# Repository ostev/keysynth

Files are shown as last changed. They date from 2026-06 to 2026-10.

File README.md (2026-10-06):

# KeySynth

KeySynth is an equation synthesiser built around a traditional mechanical keyboard!

An equation synthesiser is a wavetable synthesiser that allows the user to input arbitrary mathematical expressions which can then be used to create sounds! It also features a basic low-pass filter, with more effects (hopefully) to come.

In addition, it can act as a regular computer keyboard.

This repository contains the open-source PCBs (missing non-open source components from UltraLibrarian and SnapMagic) as well as project's source code. The PCB contains an 80% keyboard, three knobs, a pinout for a display, an ESP32-S3 (used for audio, display and USB) and an RP2040 (used for interfacing with the keyboard matrix due to limited pin availability).

The source code is divided into the following crates:

- [`calc`](crates/calc/) for the tiny programming language used for synthesis,
- [`repl`](crates/repl/) for a simple REPL for `calc` which is used for debugging and implementing new langauge features,
- [`synth`](crates/synth/) for the audio engine,
- [`keyboard_protocol`](crates/keyboard_protocol/) for interfacing between the RP2040 and the ESP32-S3 about keyboards and two of the three knobs over UART serial,
- [`keyboard_rp2040`](crates/keyboard_rp2040/) for running the keyboard matrix on the RP2040, and
- [`app`](crates/app/) for running the main application on the ESP32-S3.

## Demo

There'll be a link to a video demo up on YouTube once I've filmed it.

## :construction: :construction: :construction: Roadmap

This project isn't finished! Equation synthesis and keyboard input all work, but I want to implement some more features before considering it complete:

- [ ] USB MIDI input from host
- [ ] Improve PCB layout (as-is there are a couple of design flaws that don't inhabit the current set of functionality but limit the utility of 3.5mm audio output. I'm not sure when I'll be able to fix this: it'll be when I've made enough changes that I can justify the cost of ordering another set of PCBs.)
- [ ] Add more audio effects, like reverb and chorus.
- [ ] Add more audio synthesis engines, like subtractive or FM synthesis.

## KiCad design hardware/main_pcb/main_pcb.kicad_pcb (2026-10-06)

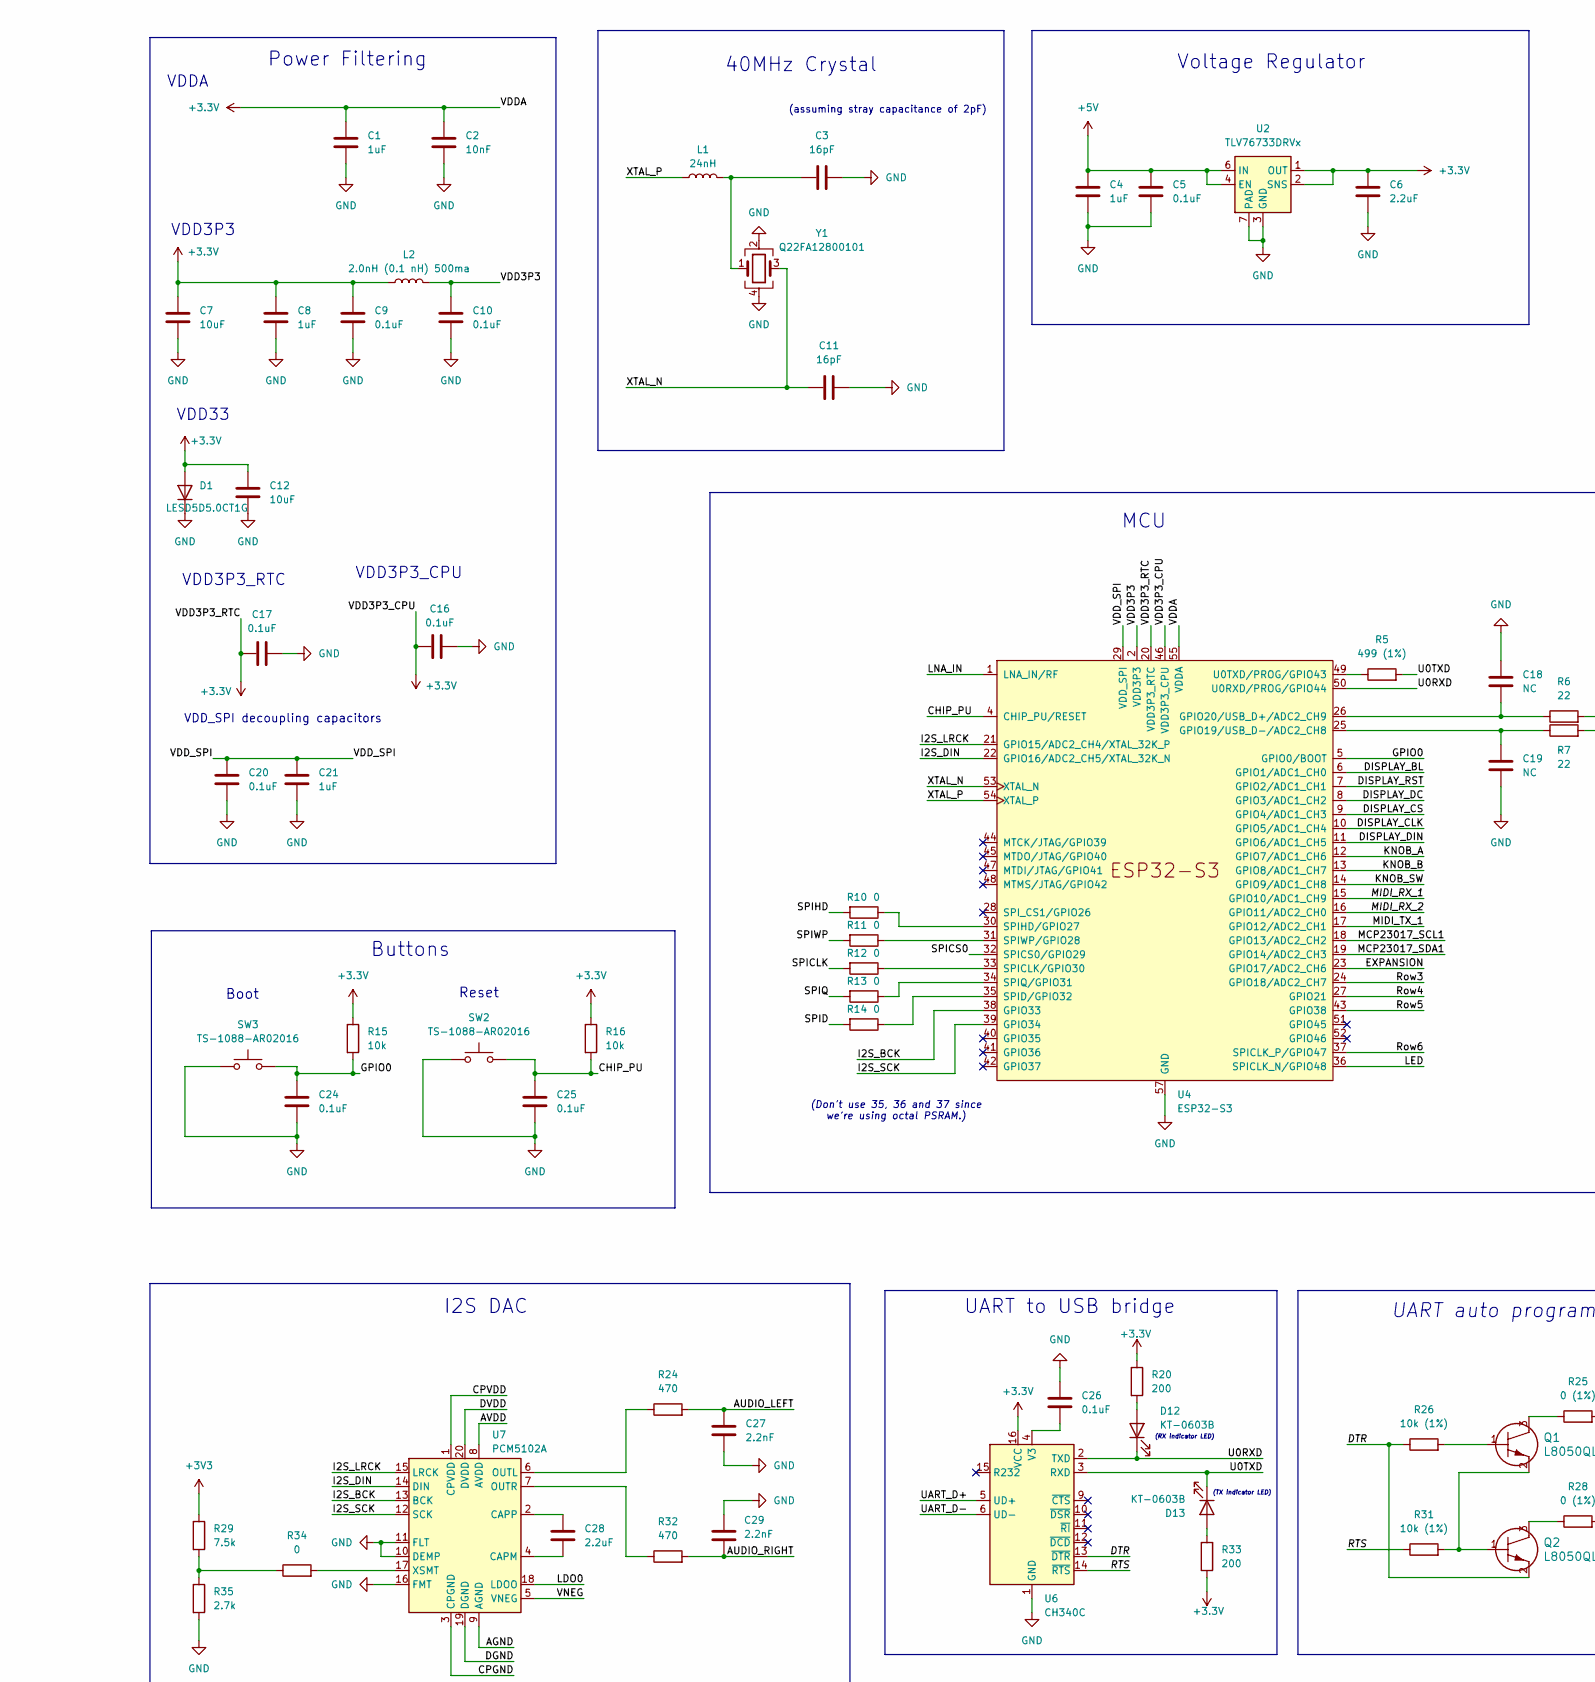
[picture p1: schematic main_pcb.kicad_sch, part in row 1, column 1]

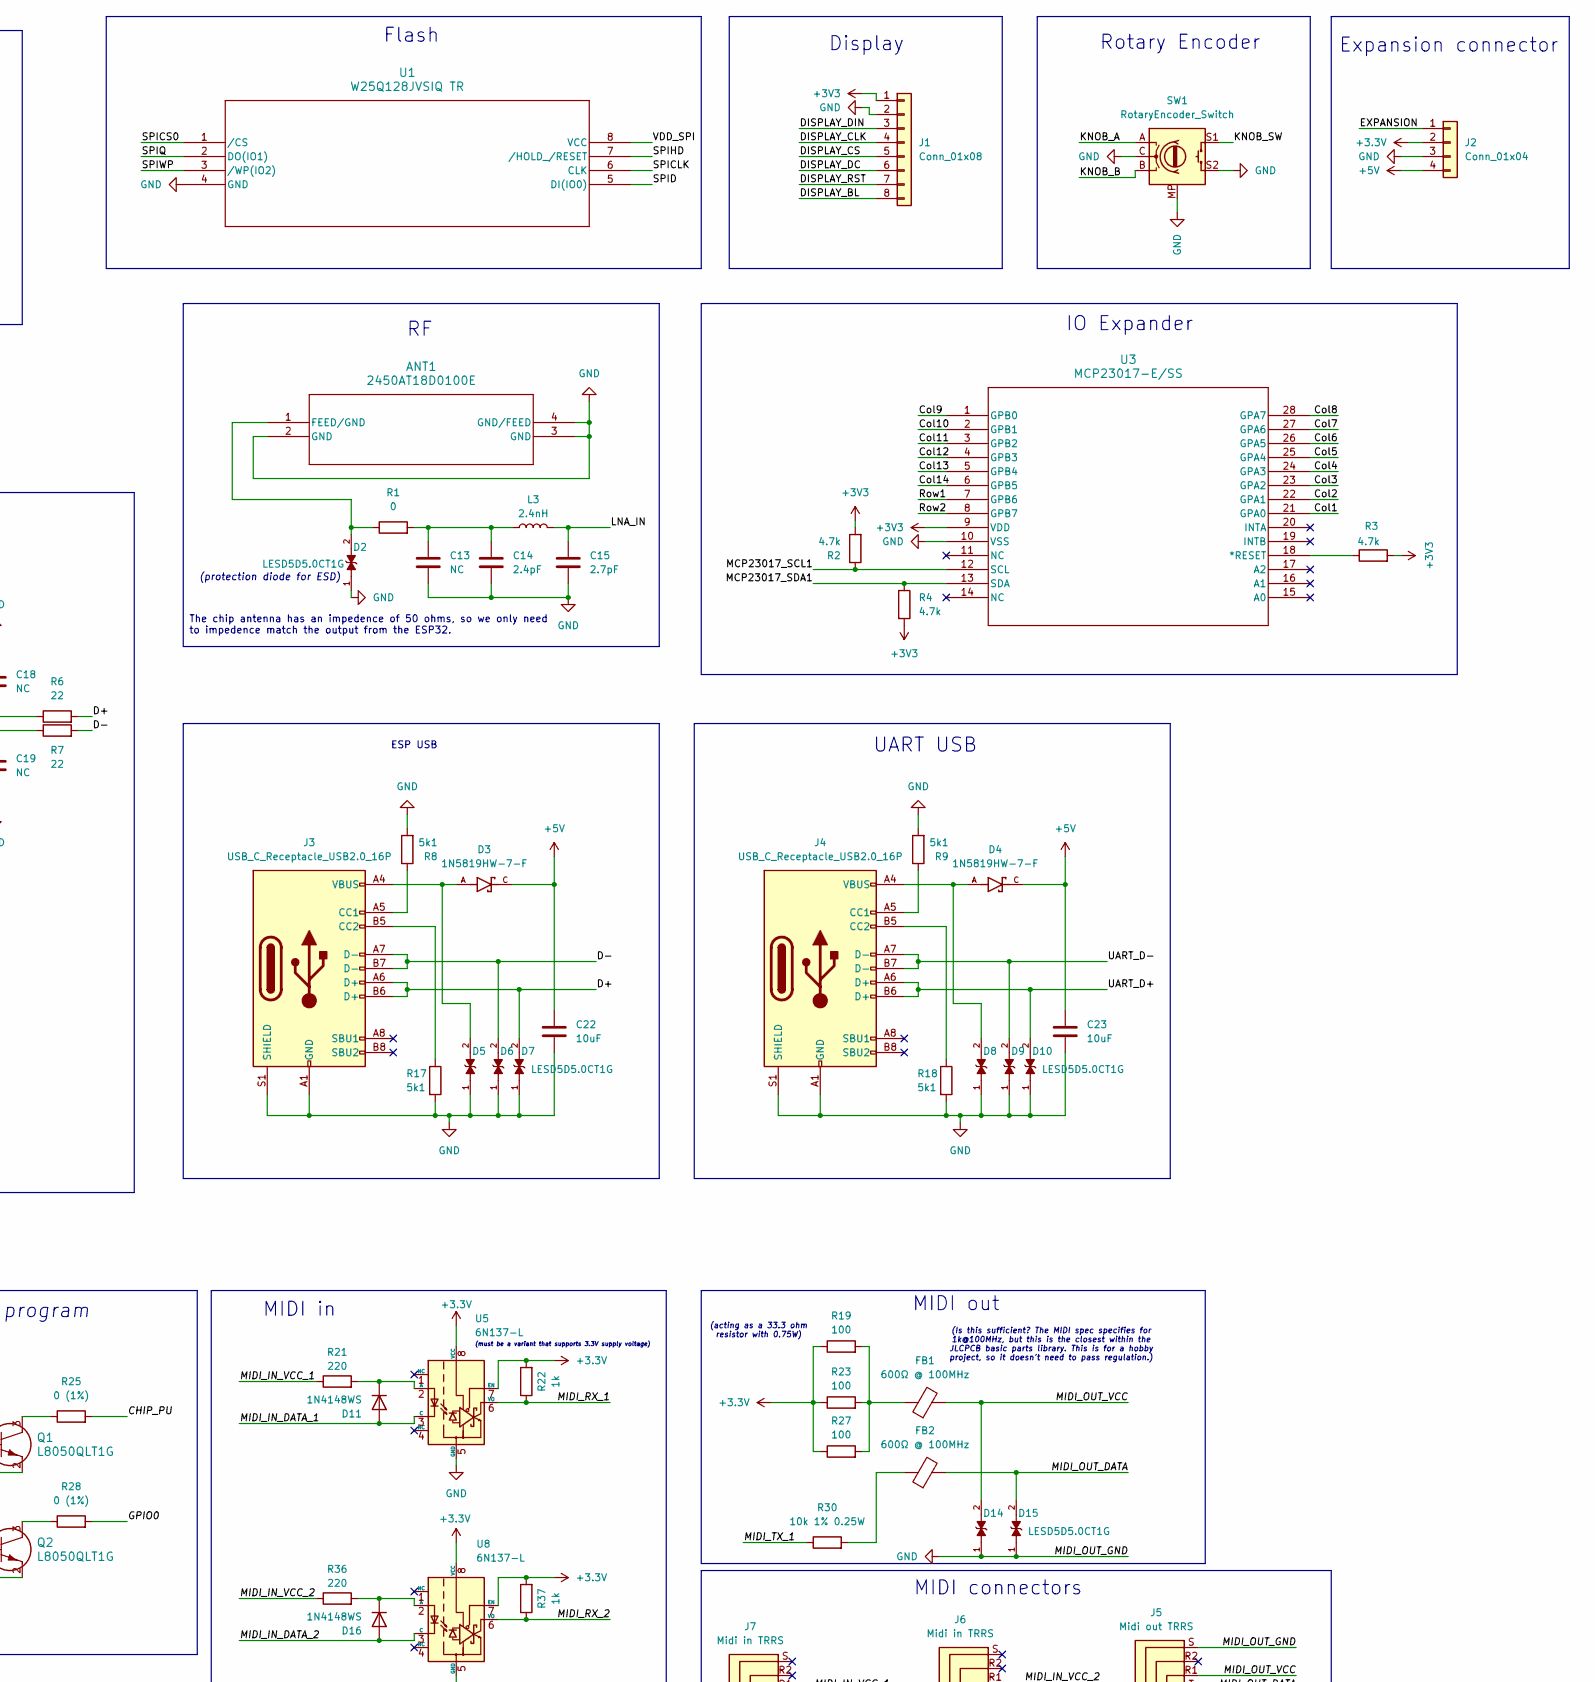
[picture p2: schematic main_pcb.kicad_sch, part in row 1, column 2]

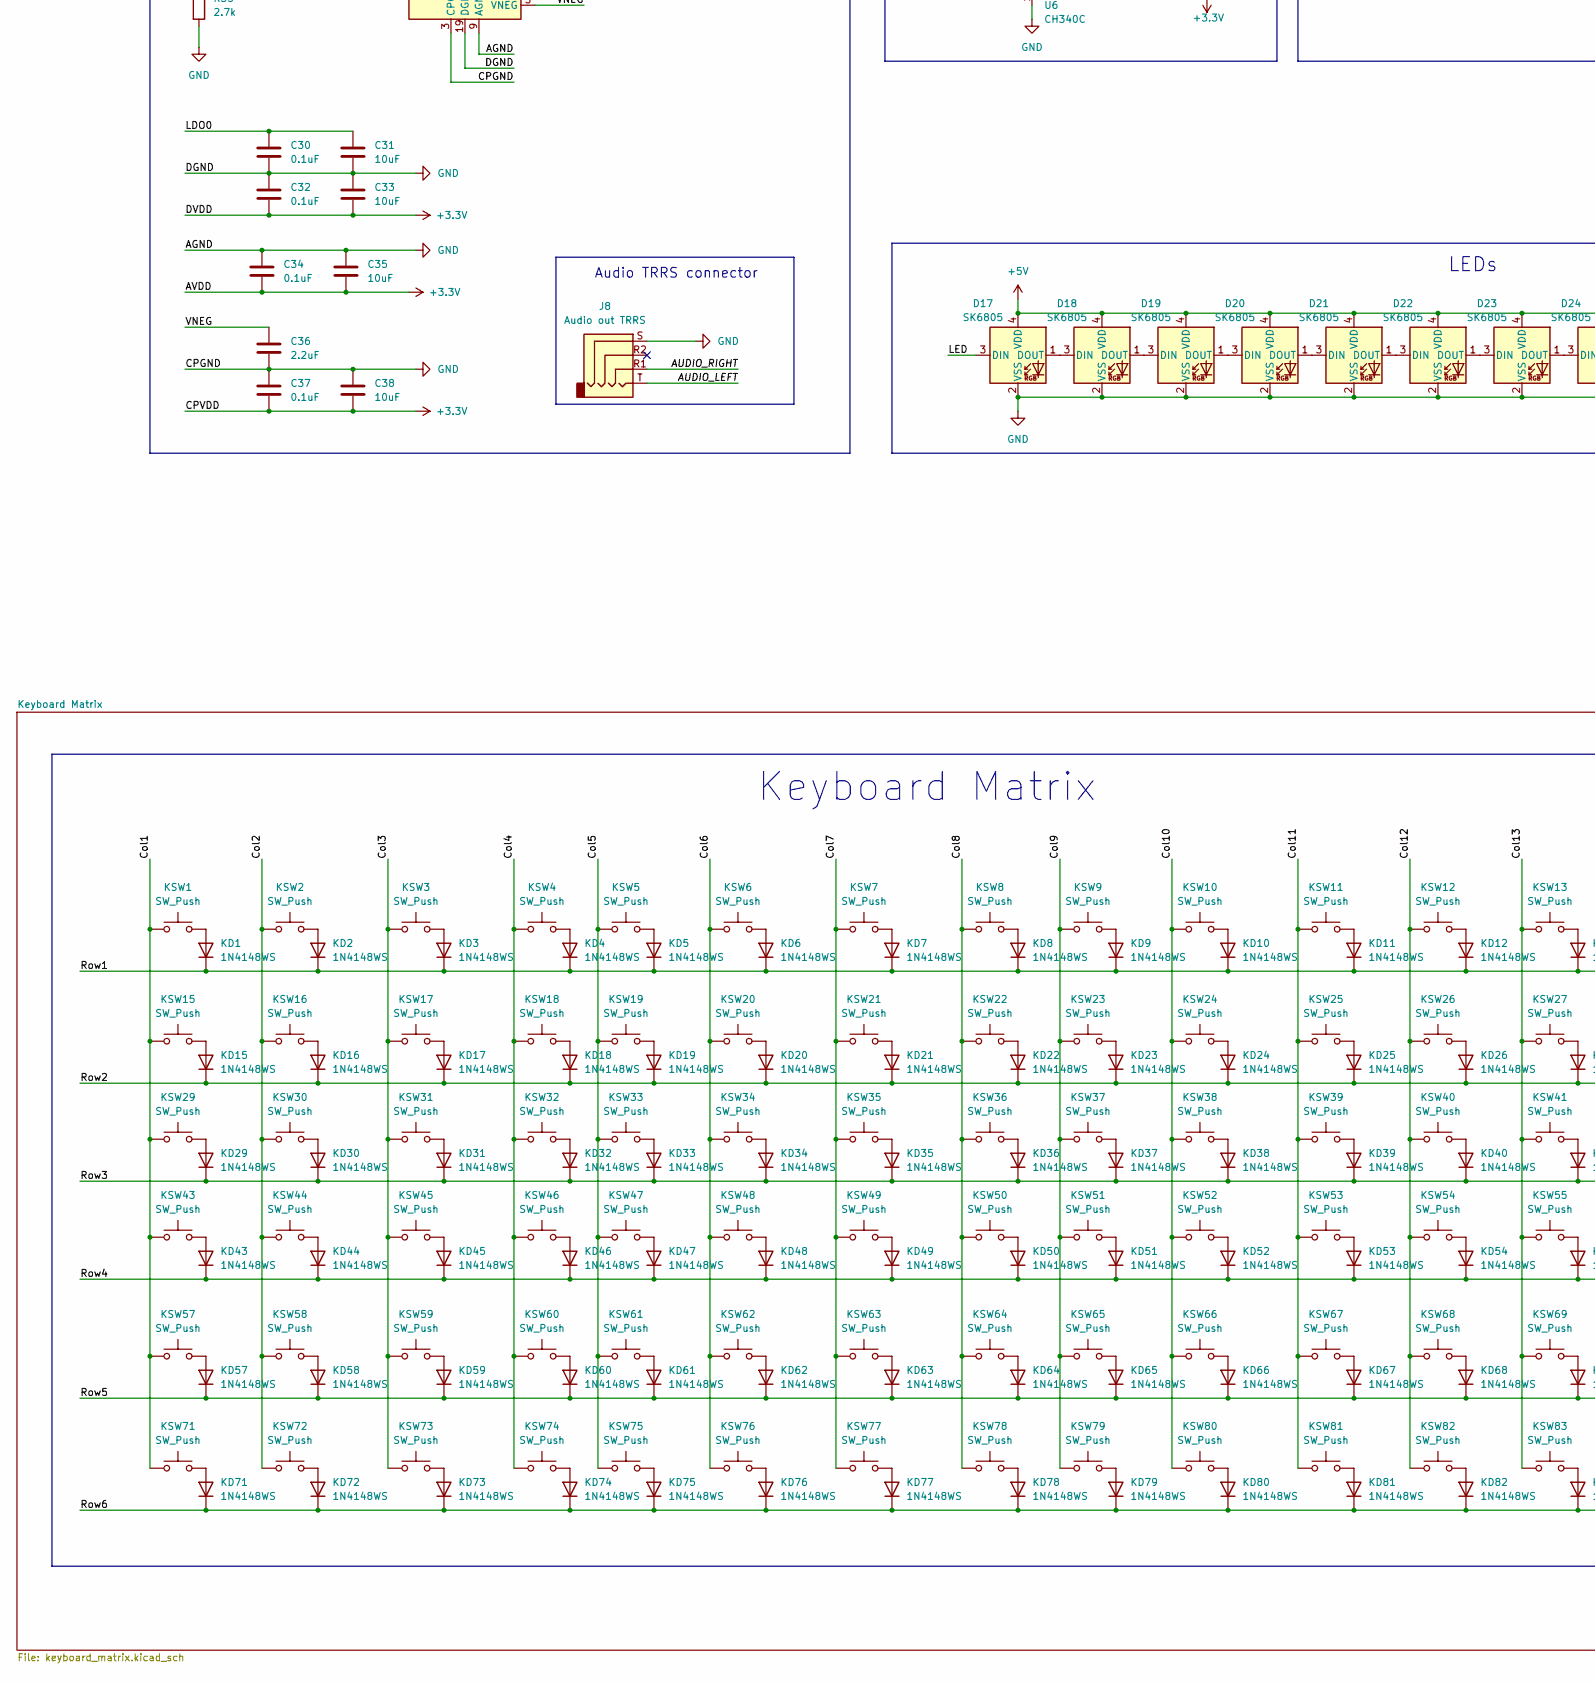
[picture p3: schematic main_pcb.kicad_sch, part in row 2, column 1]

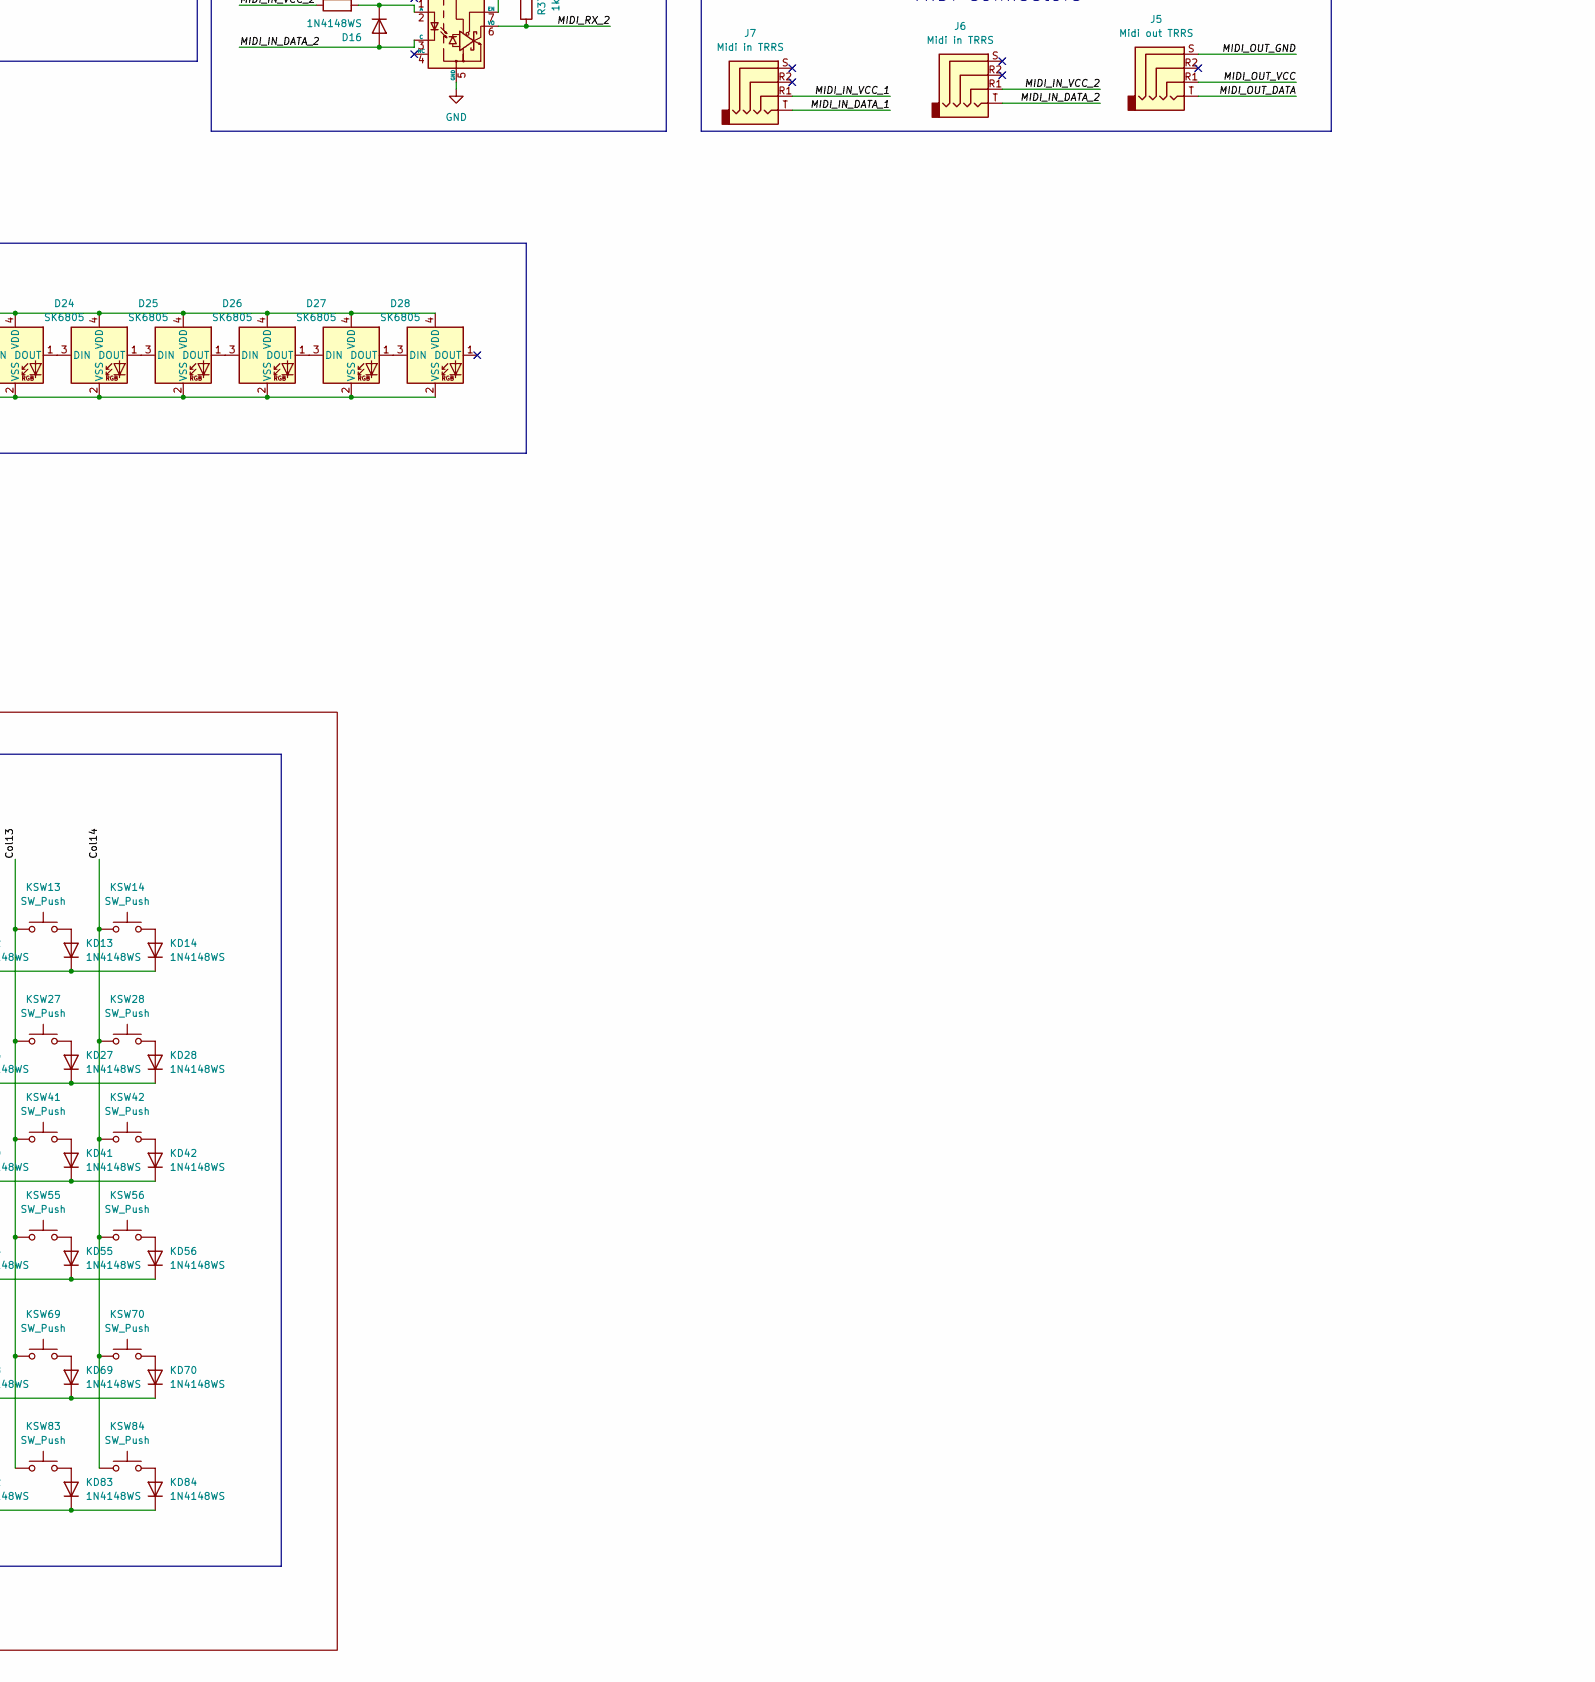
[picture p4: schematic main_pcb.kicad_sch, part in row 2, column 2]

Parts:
ANT1: 2450AT18D0100E; 2450AT18D0100E_JOT
C1, C8, C21: 1uF; C_0603_1608Metric
C2: 10nF; C_0402_1005Metric
C3, C11: 16pF; C_0603_1608Metric
C4: 1uF; C_0402_1005Metric
C5, C10, C24, C25, C26, C30, C32, C34, C37: 0.1uF; C_0402_1005Metric
C6: 2.2uF; C_0402_1005Metric
C7, C12, C22, C23: 10uF; C_0603_1608Metric
C9, C16, C17, C20: 0.1uF; C_0603_1608Metric
C13, C18, C19: NC; C_0805_2012Metric_Pad1.18x1.45mm_HandSolder
C14: 2.4pF; C_0603_1608Metric
C15: 2.7pF; C_0603_1608Metric
C27, C29: 2.2nF; C_0603_1608Metric
C28, C36: 2.2uF; C_0603_1608Metric
C31, C33, C35, C38: 10uF; C_0402_1005Metric
D1: LESD5D5.0CT1G; TVS_LESD5D5.0CT1G
D2, D5, D6, D7, D8, D9, D10, D14, D15: LESD5D5.0CT1G; TVS_LESD5D5.0CT1G; PARTREV O
D3, D4: 1N5819HW-7-F; SOD3715X145N; PARTREV 18-2
D11, D16: 1N4148WS; D_SOD-323
D12, D13: KT-0603B; LED_0603_1608Metric
D17, D18, D19, D20, D21, D22, D23, D24, D25, D26, D27, D28: SK6805; LED_SK6805_PLCC4_2.4x2.7mm_P1.3mm
FB1, FB2: 600Ω @ 100MHz; L_0805_2012Metric
J1: Conn_01x08; PinHeader_1x08_P1.00mm_Vertical
J2: Conn_01x04; PinHeader_1x04_P2.54mm_Vertical
J3, J4: USB_C_Receptacle_USB2.0_16P; USB_C_Receptacle_HRO_TYPE-C-31-M-12; LCSC C165948
J5: Midi out TRRS; Jack_3.5mm_PJ320D_Horizontal
J6, J7: Midi in TRRS; Jack_3.5mm_PJ320D_Horizontal
J8: Audio out TRRS; Jack_3.5mm_PJ320D_Horizontal
KD1, KD2, KD3, KD4, KD5, KD6, KD7, KD8, KD9, KD10, KD11, KD12, KD13, KD14, KD15, KD16, KD17, KD18, KD19, KD20, KD21, KD22, KD23, KD24, KD25, KD26, KD27, KD28, KD29, KD30, KD31, KD32, KD33, KD34, KD35, KD36, KD37, KD38, KD39, KD40, KD41, KD42, KD43, KD44, KD45, KD46, KD47, KD48, KD49, KD50, KD51, KD52, KD53, KD54, KD55, KD56, KD57, KD58, KD59, KD60, KD61, KD62, KD63, KD64, KD65, KD66, KD67, KD68, KD69, KD70, KD71, KD72, KD73, KD74, KD75, KD76, KD77, KD78, KD79, KD80, KD81, KD82, KD83, KD84: 1N4148WS; D_SOD-323; LCSC C2128
KSW1, KSW2, KSW3, KSW4, KSW5, KSW6, KSW7, KSW8, KSW9, KSW10, KSW11, KSW12, KSW13, KSW14, KSW15, KSW16, KSW17, KSW18, KSW19, KSW20, KSW21, KSW22, KSW23, KSW24, KSW25, KSW26, KSW27, KSW28, KSW29, KSW30, KSW31, KSW32, KSW33, KSW34, KSW35, KSW36, KSW37, KSW38, KSW39, KSW40, KSW41, KSW42, KSW43, KSW44, KSW45, KSW46, KSW47, KSW48, KSW49, KSW50, KSW51, KSW52, KSW53, KSW54, KSW55, KSW56, KSW57, KSW58, KSW59, KSW60, KSW61, KSW62, KSW63, KSW64, KSW65, KSW66, KSW67, KSW68, KSW69, KSW70, KSW71, KSW72, KSW73, KSW74, KSW75, KSW76, KSW77, KSW78, KSW79, KSW80, KSW81, KSW82, KSW83, KSW84: SW_Push; SW_Cherry_MX_PCB_1.00u
L1: 24nH; L_0805_2012Metric
L2: 2.0nH (0.1 nH) 500ma; L_0402_1005Metric
L3: 2.4nH; L_0201_0603Metric
Q1, Q2: L8050QLT1G; SOT-23_LRC
R1: 0; R_0402_1005Metric
R2, R3, R4: 4.7k; R_0402_1005Metric
R5: 499 (1%); R_0402_1005Metric
R6, R7: 22; R_0402_1005Metric
R8, R9: 5k1; R_0402_1005Metric; LCSC C2021
R10, R11, R12, R13, R14, R34: 0; R_1206_3216Metric
R15, R16: 10k; R_0603_1608Metric
R17, R18: 5k1; R_0402_1005Metric
R19, R23, R27: 100; R_1206_3216Metric
R20, R33: 200; R_0402_1005Metric
R21, R36: 220; R_0603_1608Metric
R22, R37: 1k; R_0603_1608Metric
R24, R32: 470; R_0805_2012Metric
R25, R28: 0 (1%); R_1206_3216Metric
R26, R31: 10k (1%); R_0402_1005Metric
R29: 7.5k; R_0603_1608Metric
R30: 10k 1% 0.25W; R_1206_3216Metric
R35: 2.7k; R_0603_1608Metric
SW1: RotaryEncoder_Switch; RotaryEncoder_Alps_EC12E-Switch_Vertical_H20mm
SW2, SW3: TS-1088-AR02016; SW_TS-1088-AR02016
U1: W25Q128JVSIQ TR; SOIC_208MIL_WIN
U2: TLV76733DRVx; WSON-6-1EP_2x2mm_P0.65mm_EP1x1.6mm_ThermalVias
U3: MCP23017-E/SS; SSOP28_MC_MCH
U4: ESP32-S3; QFN-56-1EP_7x7mm_P0.4mm_EP5.6x5.6mm
U5, U8: 6N137-L; DIP-8_W7.62mm
U6: CH340C; SOIC-16_3.9x9.9mm_P1.27mm
U7: PCM5102A; TSSOP-20_4.4x6.5mm_P0.65mm
Y1: Q22FA12800101; Crystal_SMD_2016-4Pin_2.0x1.6mm

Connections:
+3.3V: C1.1, C2.1, C6.1, C7.1, C8.1, C9.1, C12.1, C16.1, C17.1, C32.2, C33.2, C34.2, C35.2, C37.2, C38.2, D1.2 (A), J2.2, L2.1, R15.1, R16.1, R19.1, R20.1, R22.2, R23.1, R27.1, R33.1, R37.2, U2.1 (OUT), U2.2 (SNS), U4.20 (VDD3P3_RTC), U4.46 (VDD3P3_CPU), U4.55 (VDDA), U4.56 (VDDA), U5.7 (EN), U5.8 (VCC), U6.16 (VCC), U7.1 (CPVDD), U7.8 (AVDD), U7.20 (DVDD), U8.7 (EN), U8.8 (VCC)
+3V3: J1.1, R2.2, R3.2, R4.2, R29.1, U3.9 (VDD)
+5V: C4.1, C5.1, C22.1, C23.1, D3.C, D4.C, D17.4 (VDD), D18.4 (VDD), D19.4 (VDD), D20.4 (VDD), D21.4 (VDD), D22.4 (VDD), D23.4 (VDD), D24.4 (VDD), D25.4 (VDD), D26.4 (VDD), D27.4 (VDD), D28.4 (VDD), J2.4, U2.4 (EN), U2.6 (IN)
/AUDIO_LEFT: C27.1, J8.T, R24.2
/AUDIO_RIGHT: C29.2, J8.R1, R32.2
/CHIP_PU: C25.1, R16.2, R25.2, SW2.2, U4.4 (CHIP_PU/RESET)
/Col1: KSW1.1, KSW15.1, KSW29.1, KSW43.1, KSW57.1, KSW71.1, U3.21 (GPA0)
/Col2: KSW2.1, KSW16.1, KSW30.1, KSW44.1, KSW58.1, KSW72.1, U3.22 (GPA1)
/Col3: KSW3.1, KSW17.1, KSW31.1, KSW45.1, KSW59.1, KSW73.1, U3.23 (GPA2)
/Col4: KSW4.1, KSW18.1, KSW32.1, KSW46.1, KSW60.1, KSW74.1, U3.24 (GPA3)
/Col5: KSW5.1, KSW19.1, KSW33.1, KSW47.1, KSW61.1, KSW75.1, U3.25 (GPA4)
/Col6: KSW6.1, KSW20.1, KSW34.1, KSW48.1, KSW62.1, KSW76.1, U3.26 (GPA5)
/Col7: KSW7.1, KSW21.1, KSW35.1, KSW49.1, KSW63.1, KSW77.1, U3.27 (GPA6)
/Col8: KSW8.1, KSW22.1, KSW36.1, KSW50.1, KSW64.1, KSW78.1, U3.28 (GPA7)
/Col9: KSW9.1, KSW23.1, KSW37.1, KSW51.1, KSW65.1, KSW79.1, U3.1 (GPB0)
/Col10: KSW10.1, KSW24.1, KSW38.1, KSW52.1, KSW66.1, KSW80.1, U3.2 (GPB1)
/Col11: KSW11.1, KSW25.1, KSW39.1, KSW53.1, KSW67.1, KSW81.1, U3.3 (GPB2)
/Col12: KSW12.1, KSW26.1, KSW40.1, KSW54.1, KSW68.1, KSW82.1, U3.4 (GPB3)
/Col13: KSW13.1, KSW27.1, KSW41.1, KSW55.1, KSW69.1, KSW83.1, U3.5 (GPB4)
/Col14: KSW14.1, KSW28.1, KSW42.1, KSW56.1, KSW70.1, KSW84.1, U3.6 (GPB5)
/D+: D7.2, J3.A6 (D+), J3.B6 (D+), R6.2
/D-: D6.2, J3.A7 (D-), J3.B7 (D-), R7.2
/DISPLAY_BL: J1.8, U4.6 (GPIO1/ADC1_CH0)
/DISPLAY_CLK: J1.4, U4.10 (GPIO5/ADC1_CH4)
/DISPLAY_CS: J1.5, U4.9 (GPIO4/ADC1_CH3)
/DISPLAY_DC: J1.6, U4.8 (GPIO3/ADC1_CH2)
/DISPLAY_DIN: J1.3, U4.11 (GPIO6/ADC1_CH5)
/DISPLAY_RST: J1.7, U4.7 (GPIO2/ADC1_CH1)
/DTR: Q2.2, R26.1, U6.13 (~DTR)
/EXPANSION: J2.1, U4.23 (GPIO17/ADC2_CH6)
/GPIO0: C24.1, R15.2, R28.2, SW3.2, U4.5 (GPIO0/BOOT)
/I2S_BCK: U4.38 (GPIO33), U7.13 (BCK)
/I2S_DIN: U4.22 (GPIO16/ADC2_CH5/XTAL_32K_N), U7.14 (DIN)
/I2S_LRCK: U4.21 (GPIO15/ADC2_CH4/XTAL_32K_P), U7.15 (LRCK)
/I2S_SCK: U4.39 (GPIO34), U7.12 (SCK)
/KNOB_A: SW1.A, U4.12 (GPIO7/ADC1_CH6)
/KNOB_B: SW1.B, U4.13 (GPIO8/ADC1_CH7)
/KNOB_SW: SW1.S1, U4.14 (GPIO9/ADC1_CH8)
/LDO0: C30.1, C31.1, U7.18 (LDOO)
/LED: D17.3 (DIN), U4.36 (SPICLK_N/GPIO48)
/LNA_IN: C15.1, L3.2, U4.1 (LNA_IN/RF)
/MCP23017_SCL1: R2.1, U3.12 (SCL), U4.18 (GPIO13/ADC2_CH2)
/MCP23017_SDA1: R4.1, U3.13 (SDA), U4.19 (GPIO14/ADC2_CH3)
/MIDI_IN_DATA_1: D11.2 (A), J7.T, U5.3 (C)
/MIDI_IN_DATA_2: D16.2 (A), J6.T, U8.3 (C)
/MIDI_IN_VCC_1: J7.R1, R21.1
/MIDI_IN_VCC_2: J6.R1, R36.1
/MIDI_OUT_DATA: D15.2, FB2.2, J5.T
/MIDI_OUT_VCC: D14.2, FB1.2, J5.R1
/MIDI_RX_1: R22.1, U4.15 (GPIO10/ADC1_CH9), U5.6 (VO)
/MIDI_RX_2: R37.1, U4.16 (GPIO11/ADC2_CH0), U8.6 (VO)
/MIDI_TX_1: R30.1, U4.17 (GPIO12/ADC2_CH1)
/RTS: R31.1, U6.14 (~RTS)
/Row1: KD1.1 (K), KD2.1 (K), KD3.1 (K), KD4.1 (K), KD5.1 (K), KD6.1 (K), KD7.1 (K), KD8.1 (K), KD9.1 (K), KD10.1 (K), KD11.1 (K), KD12.1 (K), KD13.1 (K), KD14.1 (K), U3.7 (GPB6)
/Row2: KD15.1 (K), KD16.1 (K), KD17.1 (K), KD18.1 (K), KD19.1 (K), KD20.1 (K), KD21.1 (K), KD22.1 (K), KD23.1 (K), KD24.1 (K), KD25.1 (K), KD26.1 (K), KD27.1 (K), KD28.1 (K), U3.8 (GPB7)
/Row3: KD29.1 (K), KD30.1 (K), KD31.1 (K), KD32.1 (K), KD33.1 (K), KD34.1 (K), KD35.1 (K), KD36.1 (K), KD37.1 (K), KD38.1 (K), KD39.1 (K), KD40.1 (K), KD41.1 (K), KD42.1 (K), U4.24 (GPIO18/ADC2_CH7)
/Row4: KD43.1 (K), KD44.1 (K), KD45.1 (K), KD46.1 (K), KD47.1 (K), KD48.1 (K), KD49.1 (K), KD50.1 (K), KD51.1 (K), KD52.1 (K), KD53.1 (K), KD54.1 (K), KD55.1 (K), KD56.1 (K), U4.27 (GPIO21)
/Row5: KD57.1 (K), KD58.1 (K), KD59.1 (K), KD60.1 (K), KD61.1 (K), KD62.1 (K), KD63.1 (K), KD64.1 (K), KD65.1 (K), KD66.1 (K), KD67.1 (K), KD68.1 (K), KD69.1 (K), KD70.1 (K), U4.43 (GPIO38)
/Row6: KD71.1 (K), KD72.1 (K), KD73.1 (K), KD74.1 (K), KD75.1 (K), KD76.1 (K), KD77.1 (K), KD78.1 (K), KD79.1 (K), KD80.1 (K), KD81.1 (K), KD82.1 (K), KD83.1 (K), KD84.1 (K), U4.37 (SPICLK_P/GPIO47)
/SPICLK: R12.2, U1.6 (CLK)
/SPICS0: U1.1 (/CS), U4.32 (SPICS0/GPIO29)
/SPID: R14.2, U1.5 (DI(IO0))
/SPIHD: R10.2, U1.7 (/HOLD_/RESET)
/SPIQ: R13.2, U1.2 (DO(IO1))
/SPIWP: R11.2, U1.3 (/WP(IO2))
/U0RXD: D12.1 (K), U4.50 (U0RXD/PROG/GPIO44), U6.2 (TXD)
/U0TXD: D13.1 (K), R5.2, U6.3 (RXD)
/UART_D+: D10.2, J4.A6 (D+), J4.B6 (D+), U6.5 (UD+)
/UART_D-: D9.2, J4.A7 (D-), J4.B7 (D-), U6.6 (UD-)
/VDD_SPI: C20.1, C21.1, U1.8 (VCC), U4.29 (VDD_SPI)
/VNEG: C36.1, U7.5 (VNEG)
/XTAL_N: C11.2, U4.53 (XTAL_N), Y1.3
/XTAL_P: L1.1, U4.54 (XTAL_P)
GND: ANT1.2 (GND), ANT1.3 (GND), ANT1.4 (GND/FEED), C1.2, C2.2, C3.1, C4.2, C5.2, C6.2, C7.2, C8.2, C9.2, C10.2, C11.1, C12.2, C13.2, C14.2, C15.2, C16.2, C17.2, C18.1, C19.2, C20.2, C21.2, C22.2, C23.2, C24.2, C25.2, C26.1, C27.2, C29.1, C30.2, C31.2, C32.1, C33.1, C34.1, C35.1, C36.2, C37.1, C38.1, D1.1 (K), D2.1, D5.1, D6.1, D7.1, D8.1, D9.1, D10.1, D14.1, D15.1, D17.2 (VSS), D18.2 (VSS), D19.2 (VSS), D20.2 (VSS), D21.2 (VSS), D22.2 (VSS), D23.2 (VSS), D24.2 (VSS), D25.2 (VSS), D26.2 (VSS), D27.2 (VSS), D28.2 (VSS), J1.2, J2.3, J3.A1 (GND), J3.A12 (GND), J3.B1 (GND), J3.B12 (GND), J3.S1 (SHIELD), J4.A1 (GND), J4.A12 (GND), J4.B1 (GND), J4.B12 (GND), J4.S1 (SHIELD), J5.S, J8.S, R8.2, R9.2, R17.2, R18.2, R35.2, SW1.C, SW1.MP, SW1.S2, SW2.1, SW3.1, U1.4 (GND), U2.3 (GND), U2.5 (GND), U2.7 (PAD), U3.10 (VSS), U4.57 (GND), U5.5 (GND), U6.1 (GND), U7.3 (CPGND), U7.9 (AGND), U7.10 (DEMP), U7.11 (FLT), U7.16 (FMT), U7.19 (DGND), U8.5 (GND), Y1.2, Y1.4
unnamed: ANT1.1 (FEED/GND), D2.2, R1.1
unnamed: C3.2, L1.2, Y1.1
unnamed: C13.1, C14.1, L3.1, R1.2
unnamed: D3.A, D5.2, J3.A4 (VBUS), J3.A9 (VBUS), J3.B4 (VBUS), J3.B9 (VBUS)
unnamed: D4.A, D8.2, J4.A4 (VBUS), J4.A9 (VBUS), J4.B4 (VBUS), J4.B9 (VBUS)
unnamed: D11.1 (K), R21.2, U5.2 (A)
unnamed: D12.2 (A), R20.2
unnamed: D13.2 (A), R33.2
unnamed: D16.1 (K), R36.2, U8.2 (A)
unnamed: D17.1 (DOUT), D18.3 (DIN)
unnamed: D18.1 (DOUT), D19.3 (DIN)
unnamed: D19.1 (DOUT), D20.3 (DIN)
unnamed: D20.1 (DOUT), D21.3 (DIN)
unnamed: D21.1 (DOUT), D22.3 (DIN)
unnamed: D22.1 (DOUT), D23.3 (DIN)
unnamed: D23.1 (DOUT), D24.3 (DIN)
unnamed: D24.1 (DOUT), D25.3 (DIN)
unnamed: D25.1 (DOUT), D26.3 (DIN)
unnamed: D26.1 (DOUT), D27.3 (DIN)
unnamed: D27.1 (DOUT), D28.3 (DIN)
unnamed: FB1.1, R19.2, R23.2, R27.2
unnamed: FB2.1, R30.2
unnamed: J3.A5 (CC1), R8.1
unnamed: J3.B5 (CC2), R17.1
unnamed: J4.A5 (CC1), R9.1
unnamed: J4.B5 (CC2), R18.1
unnamed: KD1.2 (A), KSW1.2
unnamed: KD2.2 (A), KSW2.2
unnamed: KD3.2 (A), KSW3.2
unnamed: KD4.2 (A), KSW4.2
unnamed: KD5.2 (A), KSW5.2
unnamed: KD6.2 (A), KSW6.2
unnamed: KD7.2 (A), KSW7.2
unnamed: KD8.2 (A), KSW8.2
unnamed: KD9.2 (A), KSW9.2
unnamed: KD10.2 (A), KSW10.2
unnamed: KD11.2 (A), KSW11.2
unnamed: KD12.2 (A), KSW12.2
unnamed: KD13.2 (A), KSW13.2
unnamed: KD14.2 (A), KSW14.2
unnamed: KD15.2 (A), KSW15.2
unnamed: KD16.2 (A), KSW16.2
unnamed: KD17.2 (A), KSW17.2
unnamed: KD18.2 (A), KSW18.2
unnamed: KD19.2 (A), KSW19.2
unnamed: KD20.2 (A), KSW20.2
unnamed: KD21.2 (A), KSW21.2
unnamed: KD22.2 (A), KSW22.2
unnamed: KD23.2 (A), KSW23.2
unnamed: KD24.2 (A), KSW24.2
unnamed: KD25.2 (A), KSW25.2
unnamed: KD26.2 (A), KSW26.2
unnamed: KD27.2 (A), KSW27.2
unnamed: KD28.2 (A), KSW28.2
unnamed: KD29.2 (A), KSW29.2
unnamed: KD30.2 (A), KSW30.2
unnamed: KD31.2 (A), KSW31.2
unnamed: KD32.2 (A), KSW32.2
unnamed: KD33.2 (A), KSW33.2
unnamed: KD34.2 (A), KSW34.2
unnamed: KD35.2 (A), KSW35.2
unnamed: KD36.2 (A), KSW36.2
unnamed: KD37.2 (A), KSW37.2
unnamed: KD38.2 (A), KSW38.2
unnamed: KD39.2 (A), KSW39.2
unnamed: KD40.2 (A), KSW40.2
unnamed: KD41.2 (A), KSW41.2
unnamed: KD42.2 (A), KSW42.2
unnamed: KD43.2 (A), KSW43.2
unnamed: KD44.2 (A), KSW44.2
unnamed: KD45.2 (A), KSW45.2
unnamed: KD46.2 (A), KSW46.2
unnamed: KD47.2 (A), KSW47.2
unnamed: KD48.2 (A), KSW48.2
unnamed: KD49.2 (A), KSW49.2
unnamed: KD50.2 (A), KSW50.2
unnamed: KD51.2 (A), KSW51.2
unnamed: KD52.2 (A), KSW52.2
unnamed: KD53.2 (A), KSW53.2
unnamed: KD54.2 (A), KSW54.2
unnamed: KD55.2 (A), KSW55.2
unnamed: KD56.2 (A), KSW56.2
unnamed: KD57.2 (A), KSW57.2
unnamed: KD58.2 (A), KSW58.2
unnamed: KD59.2 (A), KSW59.2
unnamed: KD60.2 (A), KSW60.2
unnamed: KD61.2 (A), KSW61.2
unnamed: KD62.2 (A), KSW62.2
unnamed: KD63.2 (A), KSW63.2
unnamed: KD64.2 (A), KSW64.2
unnamed: KD65.2 (A), KSW65.2
unnamed: KD66.2 (A), KSW66.2
unnamed: KD67.2 (A), KSW67.2
unnamed: KD68.2 (A), KSW68.2
unnamed: KD69.2 (A), KSW69.2
unnamed: KD70.2 (A), KSW70.2
unnamed: KD71.2 (A), KSW71.2
unnamed: KD72.2 (A), KSW72.2
unnamed: KD73.2 (A), KSW73.2
unnamed: KD74.2 (A), KSW74.2
unnamed: KD75.2 (A), KSW75.2
unnamed: KD76.2 (A), KSW76.2
unnamed: KD77.2 (A), KSW77.2
unnamed: KD78.2 (A), KSW78.2
unnamed: KD79.2 (A), KSW79.2
unnamed: KD80.2 (A), KSW80.2
unnamed: KD81.2 (A), KSW81.2
unnamed: KD82.2 (A), KSW82.2
unnamed: KD83.2 (A), KSW83.2
unnamed: KD84.2 (A), KSW84.2
unnamed: Q1.1, R26.2
unnamed: Q1.2, Q2.1, R31.2
unnamed: Q1.3, R25.1
unnamed: Q2.3, R28.1
unnamed: R29.2, R34.1, R35.1
unnamed: R3.1, U3.18 (*RESET)
unnamed: C19.1, R7.1, U4.25 (GPIO19/USB_D-/ADC2_CH8)
unnamed: C18.2, R6.1, U4.26 (GPIO20/USB_D+/ADC2_CH9)
unnamed: R12.1, U4.33 (SPICLK/GPIO30)
unnamed: R14.1, U4.35 (SPID/GPIO32)
unnamed: R10.1, U4.30 (SPIHD/GPIO27)
unnamed: R13.1, U4.34 (SPIQ/GPIO31)
unnamed: R11.1, U4.31 (SPIWP/GPIO28)
unnamed: R5.1, U4.49 (U0TXD/PROG/GPIO43)
unnamed: C26.2, U6.4 (V3)
unnamed: C28.2, U7.4 (CAPM)
unnamed: C28.1, U7.2 (CAPP)
unnamed: R24.1, U7.6 (OUTL)
unnamed: R32.1, U7.7 (OUTR)
unnamed: R34.2, U7.17 (XSMT)
VDD3P3: C10.1, L2.2, U4.2 (VDD3P3), U4.3 (VDD3P3)

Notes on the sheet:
(protection diode for ESD)
The chip antenna has an impedence of 50 ohms, so we only need to impedence match the output from the ESP32.
Reset
UART USB
MIDI in
IO Expander
Display
MIDI out
(Is this sufficient? The MIDI spec specifies for 1k@100MHz, but this is the closest within the JLCPCB basic parts library. This is for a hobby project, so it doesn't need to pass regulation.)
Keyboard Matrix
UART auto program
Voltage Regulator
VDD3P3
Flash
(TX indicator LED)
(acting as a 33.3 ohm resistor with 0.75W)
Power Filtering
MCU
(Don't use 35, 36 and 37 since we're using octal PSRAM.)
VDD3P3_RTC
(assuming stray capacitance of 2pF)
ESP USB
VDD3P3_CPU
Boot
Audio TRRS connector
40MHz Crystal
LEDs
UART to USB bridge
Buttons
VDD33
I2S DAC
(RX indicator LED)
Rotary Encoder
VDD_SPI decoupling capacitors
(must be a variant that supports 3.3V supply voltage)
MIDI connectors
VDDA
Expansion connector

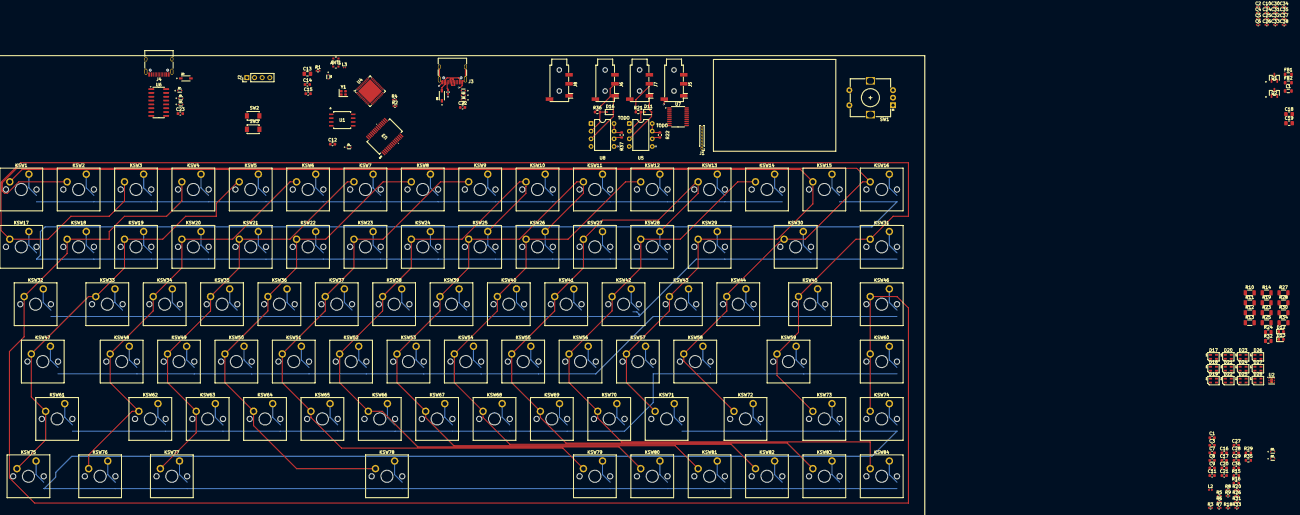
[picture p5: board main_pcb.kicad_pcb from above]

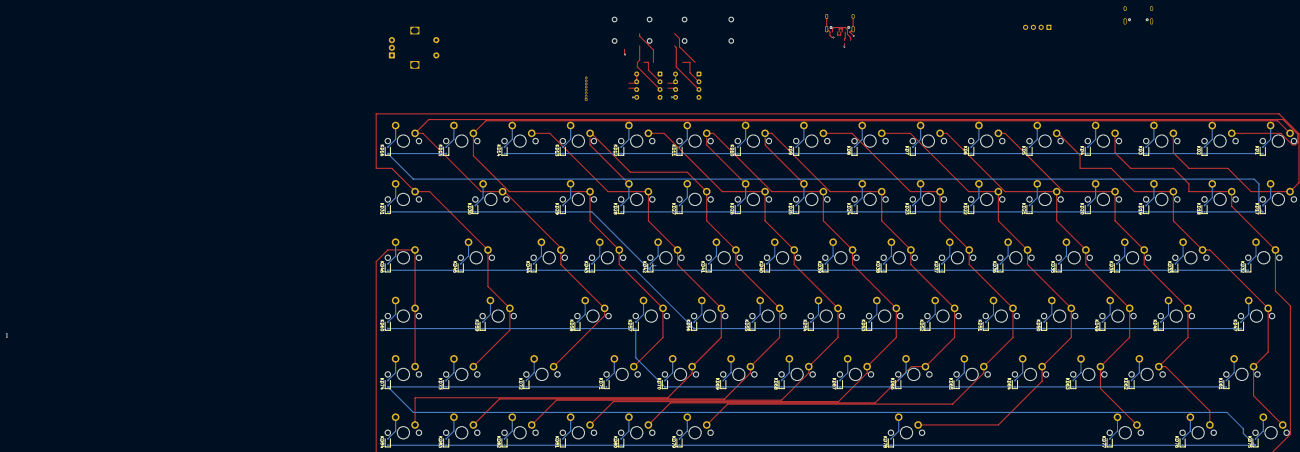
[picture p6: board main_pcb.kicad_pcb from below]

Board: 2 copper layers, 299 parts (84 on the bottom side), 205 nets.

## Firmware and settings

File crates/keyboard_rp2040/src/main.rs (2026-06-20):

#![no_std]
#![no_main]

use crate::keyboard::HardwareLayout;
use core::{
    char::MAX,
    ptr::{self, addr_of_mut},
};
use defmt::println;
use embassy_executor::{Executor, Spawner, task};
use embassy_rp::{
    bind_interrupts,
    clocks::ClockConfig,
    dma,
    gpio::{AnyPin, Input, Level, Output, Pin, Pull},
    multicore::Stack,
    peripherals::{DMA_CH0, UART0, UART1},
    pio::{self, Pio, program::pio_asm},
    uart::{self, BufferedInterruptHandler, BufferedUartTx, UartTx},
    usb::In,
};
use embassy_sync::{
    blocking_mutex::{CriticalSectionMutex, raw::CriticalSectionRawMutex},
    channel::{Channel, Sender},
};
use embassy_time::{Duration, Instant, Timer};
use embedded_hal::digital::InputPin;
use embedded_io::Write;
use enumflags2::BitFlags;
use keyboard_protocol::{
    Key, KeyboardStatus, KeyboardWithEncoderStatus, Modifier, SpecialKey,
    StandardKey::{self, A},
    layout::{self, Layout},
    uart::BAUDRATE,
};
use modular_bitfield::{
    bitfield,
    specifiers::{B7, B15},
};
use static_cell::StaticCell;

use {defmt_rtt as _, panic_probe as _};

mod encoders;
mod keyboard;

bind_interrupts!(struct Irqs {
    DMA_IRQ_0 => dma::InterruptHandler<DMA_CH0>;
});

static mut CORE1_STACK: Stack<4096> = Stack::new();
static EXECUTOR0: StaticCell<Executor> = StaticCell::new();
static EXECUTOR1: StaticCell<Executor> = StaticCell::new();

#[cortex_m_rt::entry]
fn main() -> ! {
    let peripherals = embassy_rp::init(embassy_rp::config::Config::default());

    let keyboard_hardware: HardwareLayout<{ keyboard::NUM_ROWS }, { keyboard::NUM_COLUMNS }> =
        HardwareLayout {
            rows: [
                Input::new(peripherals.PIN_19, Pull::Down),
                Input::new(peripherals.PIN_20, Pull::Down),
                Input::new(peripherals.PIN_21, Pull::Down),
                Input::new(peripherals.PIN_22, Pull::Down),
                Input::new(peripherals.PIN_23, Pull::Down),
                Input::new(peripherals.PIN_24, Pull::Down),
            ],
            columns: [
                Output::new(peripherals.PIN_18, Level::Low),
                Output::new(peripherals.PIN_17, Level::Low),
                Output::new(peripherals.PIN_16, Level::Low),
                Output::new(peripherals.PIN_15, Level::Low),
                Output::new(peripherals.PIN_14, Level::Low),
                Output::new(peripherals.PIN_13, Level::Low),
                Output::new(peripherals.PIN_12, Level::Low),
                Output::new(peripherals.PIN_11, Level::Low),
                Output::new(peripherals.PIN_10, Level::Low),
                Output::new(peripherals.PIN_9, Level::Low),
                Output::new(peripherals.PIN_8, Level::Low),
                Output::new(peripherals.PIN_7, Level::Low),
                Output::new(peripherals.PIN_6, Level::Low),
                Output::new(peripherals.PIN_5, Level::Low),
            ],
        };

    let encoder_hardware = encoders::Hardware::new(
        encoders::Unit::new(
            Input::new(peripherals.PIN_27, Pull::Up),
            Input::new(peripherals.PIN_26, Pull::Up),
        ),
        encoders::Unit::new(
            Input::new(peripherals.PIN_29, Pull::Up),
            Input::new(peripherals.PIN_28, Pull::Up),
        ),
    );

    embassy_rp::multicore::spawn_core1(
        peripherals.CORE1,
        unsafe { &mut *addr_of_mut!(CORE1_STACK) },
        move || {
            let executor1 = EXECUTOR1.init(Executor::new());
            executor1.run(|spawner| {
                spawner.spawn(poll_loop(keyboard_hardware, encoder_hardware).unwrap())
            });
        },
    );

    let executor0 = EXECUTOR0.init(Executor::new());

    let uart = UartTx::new(
        peripherals.UART1,
        peripherals.PIN_4,
        peripherals.DMA_CH0,
        Irqs,
        {
            let mut config = uart::Config::default();
            config.baudrate = BAUDRATE;

            config
        },
    );

    executor0.run(|spawner| spawner.spawn(uart_communicator(uart).unwrap()))
}

#[task]
async fn uart_communicator(mut uart: UartTx<'static, uart::Async>) {
    let receiver = CHANNEL.receiver();

    loop {
        let status = receiver.receive().await;

        let mut output_buffer = [0; core::mem::size_of::<KeyboardWithEncoderStatus>() + 2];
        {
            let message_end = output_buffer.len() - 1;
            let mut message_portion = &mut output_buffer[1..message_end];
            postcard::to_slice(&status, &mut message_portion).unwrap();
        }

        output_buffer[0] = keyboard_protocol::uart::START_BYTE;
        output_buffer[output_buffer.len() - 1] = keyboard_protocol::uart::END_BYTE;

        match uart.write(&output_buffer).await {
            Ok(_) => {}
            Err(error) => defmt::warn!(
                "Failed to send keyboard status over UART! Here's the error {:?}",
                error
            ),
        }
    }
}

static CHANNEL: Channel<CriticalSectionRawMutex, KeyboardWithEncoderStatus, 64> = Channel::new();

#[task]
pub async fn poll_loop(
    mut keyboard_hardware: HardwareLayout<{ keyboard::NUM_ROWS }, { keyboard::NUM_COLUMNS }>,
    mut encoder_hardware: encoders::Hardware<
        Input<'static>,
        Input<'static>,
        Input<'static>,
        Input<'static>,
    >,
) {
    let sender = CHANNEL.sender();
    let mut previous_keyboard_status = None;

    let mut debouncer = keyboard::Debouncer::new();

    loop {
        // First scan the keyboard matrix
        let keyboard_status = keyboard_hardware.scan(&layout::STANDARD, &mut debouncer);

        // Then scan the encoders
        let encoder_update = encoder_hardware.scan();

        // If either changed, send the status update!
        if !encoder_update.is_zero() || Some(keyboard_status) != previous_keyboard_status {
            sender
                .send(KeyboardWithEncoderStatus {
                    keyboard: keyboard_status,
                    encoder: encoder_update,
                })
                .await;
        }

        previous_keyboard_status = Some(keyboard_status);
    }
}

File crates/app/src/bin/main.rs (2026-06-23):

#![no_std]
#![no_main]
#![deny(
    clippy::mem_forget,
    reason = "mem::forget is generally not safe to do with esp_hal types, especially those \
    holding buffers for the duration of a data transfer."
)]
#![deny(clippy::large_stack_frames)]

extern crate alloc;

use esp_backtrace as _;

use app::hardware::Hardware;
use app::input::encoder;
use app::input::keyboard::keyboard_interface;
use embassy_executor::Spawner;
use esp_rtos::embassy::InterruptExecutor;
use static_cell::StaticCell;

use app::input;
use app::{gui, usb};

esp_bootloader_esp_idf::esp_app_desc!();

#[esp_rtos::main]
async fn main(spawner: Spawner) {
    let hardware = Hardware::new().await.unwrap();

    encoder::configure(hardware.encoder);

    {
        static HIGH_PRIORITY_EXECUTOR: StaticCell<InterruptExecutor<2>> = StaticCell::new();

        let high_priority_executor =
            HIGH_PRIORITY_EXECUTOR.init_with(|| InterruptExecutor::new(hardware.interrupt_2));
        let high_priority = high_priority_executor.start(esp_hal::interrupt::Priority::Priority3);

        // Start the input tasks as high-priority interrupts
        high_priority.spawn(input::router().unwrap());
        high_priority.spawn(keyboard_interface(hardware.keyboard).unwrap());
    }

    {
        static STACK: StaticCell<esp_hal::system::Stack<{ usb::STACK_SIZE }>> = StaticCell::new();

        let stack = STACK.init_with(|| esp_hal::system::Stack::new());

        esp_rtos::start_second_core(hardware.cpu_control, hardware.interrupt_1, stack, || {
            // The USB device loop fully occupies the second core
            usb::device_loop(hardware.usb)
        });
    }

    spawner.spawn(gui::app(hardware.display, hardware.storage).unwrap());
}

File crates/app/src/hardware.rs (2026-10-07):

use esp_hal::{
    Blocking,
    clock::CpuClock,
    dma::{self, DmaRxBuf, DmaTxBuf},
    dma_buffers,
    gpio::{Level, Output, OutputConfig},
    interrupt::software::{SoftwareInterrupt, SoftwareInterruptControl},
    pcnt::Pcnt,
    peripherals::{CPU_CTRL, GPIO7, GPIO8},
    psram::{FlashFreq, SpiRamFreq},
    spi::{self, master::Spi},
    time::Rate,
    timer::timg::TimerGroup,
    uart::{self, UartRx},
};
use esp_println::println;
use esp_storage::FlashStorage;
use keyboard_protocol::uart::BAUDRATE;

use crate::{
    gui::display::{self, DisplayHardware},
    input::{encoder, keyboard::KeyboardHardware},
    storage::StorageHardware,
    usb,
};

/// Contains all the hardware that the synthesiser talks to.
pub struct Hardware {
    pub interrupt_1: SoftwareInterrupt<'static, 1>,
    pub interrupt_2: SoftwareInterrupt<'static, 2>,
    pub cpu_control: CPU_CTRL<'static>,

    pub keyboard: KeyboardHardware,
    pub encoder: encoder::Hardware<GPIO7<'static>, GPIO8<'static>>,

    pub display: DisplayHardware,

    pub usb: usb::UsbHardware,
    pub storage: StorageHardware,
}

/// An error that occurred during hardware initialisation.
#[derive(Debug)]
pub enum InitError {
    UartConfigError(uart::ConfigError),
    SpiConfigError(spi::master::ConfigError),
    DmaBufError(dma::DmaBufError),
}

impl Hardware {
    pub async fn new() -> Result<Hardware, InitError> {
        let peripherals = esp_hal::init(esp_hal::Config::default().with_cpu_clock(CpuClock::max()));

        // Initialise heap memory
        esp_alloc::psram_allocator!(
            peripherals.PSRAM,
            esp_hal::psram,
            esp_hal::psram::PsramConfig {
                mode: esp_hal::psram::PsramMode::OctalSpi,
                size: esp_hal::psram::PsramSize::AutoDetect,
                core_clock: None,
                flash_frequency: FlashFreq::FlashFreq80m,
                ram_frequency: SpiRamFreq::Freq80m,
            }
        );

        let software_interrupt = SoftwareInterruptControl::new(peripherals.SW_INTERRUPT);
        let timer_group_0 = TimerGroup::new(peripherals.TIMG0);

        // Start the executor
        esp_rtos::start(timer_group_0.timer0, software_interrupt.software_interrupt0);

        // This is used later to start the second core
        let cpu_control = peripherals.CPU_CTRL;

        // UART receiver from RP2040
        let keyboard = {
            let uart = UartRx::new(
                peripherals.UART1,
                uart::Config::default().with_baudrate(BAUDRATE),
            )
            .map_err(InitError::UartConfigError)?
            .with_rx(peripherals.GPIO12);

            KeyboardHardware { uart }
        };

        println!("Keyboard setup complete!");

        // The primary encoder hardware
        let encoder = {
            encoder::Hardware {
                counter: Pcnt::new(peripherals.PCNT),
                a: peripherals.GPIO7,
                b: peripherals.GPIO8,
            }
        };

        // The SPI display driver
        let display = {
            let (rx_buffer, rx_descriptors, tx_buffer, tx_descriptors) = dma_buffers!(32_000);

            let dma_rx_buf =
                DmaRxBuf::new(rx_descriptors, rx_buffer).map_err(InitError::DmaBufError)?;
            let dma_tx_buf =
                DmaTxBuf::new(tx_descriptors, tx_buffer).map_err(InitError::DmaBufError)?;

            let spi: esp_hal::spi::master::SpiDmaBus<'static, Blocking> = Spi::new(
                peripherals.SPI2,
                spi::master::Config::default()
                    .with_frequency(Rate::from_mhz(20))
                    .with_mode(spi::Mode::_0),
            )
            .map_err(InitError::SpiConfigError)?
            .with_sck(peripherals.GPIO2)
            .with_cs(peripherals.GPIO3)
            .with_mosi(peripherals.GPIO1)
            .with_dma(peripherals.DMA_CH1)
            .with_buffers(dma_rx_buf, dma_tx_buf);

            let dc_pin = Output::new(peripherals.GPIO4, Level::Low, OutputConfig::default());
            let reset_pin = Output::new(peripherals.GPIO5, Level::Low, OutputConfig::default());

            display::DisplayHardware {
                spi,
                reset_pin,
                dc_pin,
            }
        };

        println!("Display setup complete!");

        let storage = StorageHardware {
            flash: FlashStorage::new(peripherals.FLASH),
        };

        println!("Storage setup complete!");

        let usb = usb::Peripherals {
            usb: peripherals.USB0,
            dp: peripherals.GPIO20,
            dm: peripherals.GPIO19,
        }
        .build();

        println!("USB setup complete!");

        Ok(Hardware {
            interrupt_1: software_interrupt.software_interrupt1,
            interrupt_2: software_interrupt.software_interrupt2,
            cpu_control,

            keyboard,
            encoder,
            usb,
            display,
            storage,
        })
    }
}

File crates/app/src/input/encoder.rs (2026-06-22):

use core::cell::OnceCell;

use bytemuck::NoUninit;
use embassy_sync::blocking_mutex::Mutex;
use esp_hal::{
    gpio::{Input, InputConfig, InputPin, Pull},
    handler,
    interrupt::Priority,
    pcnt::{
        Pcnt,
        channel::{CtrlMode, EdgeMode},
        unit::Unit,
    },
};
use esp_sync::RawMutex;

mod channel {
    use super::Delta;
    use crate::channel;

    channel!(Delta, 32);
}
pub use channel::receiver;

/// The amount each encoder detent changes a parameter by.
pub const STEP: f32 = 0.01;

/// Identifies the currently selected parameter panel.

#[derive(Clone, Copy, Debug, NoUninit, PartialEq, Eq, Hash, Default)]
#[repr(u8)]
pub enum Panel {
    /// Filter cutoff and resonance controls.
    #[default]
    CutoffResonance,

    /// Envelope attack and decay controls.
    AttackDecay,

    /// Envelope sustain and release controls.
    SustainRelease,
}

/// Identifies one of the rotary encoders.
#[derive(Clone, Copy, Debug, PartialEq, Eq)]
pub enum Id {
    /// The primary encoder.
    Primary,
    /// One of the two panel encoders.
    Panel(PanelId),
}

/// Identifies a panel encoder.

#[derive(Clone, Copy, Debug, PartialEq, Eq)]
pub enum PanelId {
    /// The secondary encoder.
    One,
    /// The tertiary encoder.
    Two,
}

/// The direction an encoder was rotated.

#[derive(Clone, Copy, Debug, PartialEq, Eq)]
pub enum Direction {
    /// Clockwise rotation.
    Increase,
    /// Counter-clockwise rotation.
    Decrease,
}

impl From<Direction> for f32 {
    fn from(direction: Direction) -> Self {
        match direction {
            Direction::Increase => 1.0,
            Direction::Decrease => -1.0,
        }
    }
}

/// Hardware resources required to configure an encoder.
pub struct Hardware<A: InputPin + 'static, B: InputPin + 'static> {
    pub counter: Pcnt<'static>,
    pub a: A,
    pub b: B,
}

/// Relative movement reported by each encoder since the last update.
#[derive(Clone, Copy, Debug)]
pub struct EncoderStatus {
    pub deltas: [Delta; 3],
}

/// Signed encoder movement measured in detents.
pub type Delta = i16;

const THRESHOLD: i16 = 3;
const FILTER: u16 = 12;

/// Configures an encoder unit with thresholds, interrupts and filtering.
fn configure_unit<'d, const N: usize>(
    unit: &mut Unit<'d, N>,
    a: impl InputPin + 'd,
    b: impl InputPin + 'd,
) {
    let config = InputConfig::default().with_pull(Pull::Up);
    let input_a = Input::new(a, config);
    let input_b = Input::new(b, config);

    unit.set_low_limit(Some(-THRESHOLD)).unwrap();
    unit.set_high_limit(Some(THRESHOLD)).unwrap();
    unit.set_filter(Some(FILTER)).unwrap();

    unit.channel0.set_ctrl_signal(input_a.peripheral_input());
    unit.channel0.set_edge_signal(input_b.peripheral_input());
    unit.channel0
        .set_ctrl_mode(CtrlMode::Reverse, CtrlMode::Keep);
    unit.channel0
        .set_input_mode(EdgeMode::Increment, EdgeMode::Decrement);

    unit.channel1.set_ctrl_signal(input_b);
    unit.channel1.set_edge_signal(input_a);
    unit.channel1
        .set_ctrl_mode(CtrlMode::Reverse, CtrlMode::Keep);
    unit.channel1
        .set_input_mode(EdgeMode::Decrement, EdgeMode::Increment);

    unit.listen();
}

/// Configures the global encoder driver.
///
/// # Panics
/// Panics if the encoder driver has already been configured.
pub fn configure<A: InputPin + 'static, B: InputPin + 'static>(mut hardware: Hardware<A, B>) {
    hardware.counter.set_interrupt_handler(interrupt_handler);
    configure_unit(&mut hardware.counter.unit0, hardware.a, hardware.b);

    COUNTER.lock(|cell| {
        cell.set(hardware.counter)
            .unwrap_or_else(|_| panic!("The counter was already initialised!"))
    });
}

static COUNTER: Mutex<RawMutex, OnceCell<Pcnt<'static>>> = Mutex::new(OnceCell::new());

/// Interrupt handler for encoder movement.
#[handler(priority = Priority::Priority3)]
fn interrupt_handler() {
    let sender = channel::sender();
    let events = unsafe {
        COUNTER.lock_mut(|counter| {
            let counter = counter.get_mut().unwrap();
            let unit = &counter.unit0;

            let events = unit.events();

            unit.reset_interrupt();
            unit.clear();

            events
        })
    };

    let delta = if events.low_limit {
        -1
    } else if events.high_limit {
        1
    } else {
        0
    };
    // If the channel is full, we'll drop encoder ticks. This is fine.
    let _ = sender.try_send(delta);
}

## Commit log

2026-02-08 Start on basic wavetable oscillator
    [lib.rs]
2026-04-21 Test interpreter on the ESP32
2026-04-21 Switch interpreter to use reference-counting instead of arenas
2026-04-23 Add diagnostics for runtime errors
    [main.rs]
2026-04-25 Add parser error handling
    [lib.rs, main.rs]
2026-04-28 Add low-pass filter and envelope
2026-04-28 Write a pitch estimator
2026-05-02 Fix bug and adjust sustain
    [lib.rs]
2026-05-19 Implement UART keyboard protocol
2026-05-20 Add ESP32 dependencies
2026-05-23 Fix lifetime errors with `KeyboardStatus`
    [lib.rs]
2026-06-03 Implement initial editor prototype
2026-06-09 Add delay to hardware reset
    [display.rs, hardware.rs]
2026-06-09 Start writing custom display driver
2026-06-10 Start implementing custom display driver
2026-06-20 Add support for encoder input
2026-06-21 Start fixing issues with file select page
    [display.rs, encoder.rs, event.rs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]
2026-06-21 Fix all of the functionality issues with the text editor
    [display.rs, effect.rs]
2026-06-21 Fix select file issues
    [display.rs, effect.rs, home.rs]
2026-06-22 Add error handling to display driver
    [display.rs]
2026-10-06 Import PCBs from separate repository
    [keyboard_matrix.kicad_sch, main_pcb.kicad_pcb, main_pcb.kicad_sch]
